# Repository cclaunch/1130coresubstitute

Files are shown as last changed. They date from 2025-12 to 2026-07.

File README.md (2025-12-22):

1130 Core Substitute

This project is intended for IBM 1130 systems where a core memory compartment is nonfunctional and unlikely to be restored to reliable operation. The printed circuit board is inserted at the top of the core compartment and is connected via the top cables T1, T3 and T4 that are normally plugged into the SLT board for the compartment. 

It is based around a Magnetoresistive Random Access Memory (MRAM) which provides the same non-volatility as core memory even after two decades sitting without power. MRAM has infinite read and write cycles, unlike flash memory, thus it is very suitable for use in a computer.

One would disconnect the four voltage rails to the core memory compartment (+6, +3, -3 and +12) so that the compartment itself is inert. The new PCB fits in the space at the top of the compartment where the top cables were connected. It requires only three wires to connect it to the +12V and ground rails of the 1130 system. 

This first version was developed for a particular 1130 system I restored, one with 8K of 3.6 microsecond core. This fits in the B gate in compartment C1. The SLT board has a core memory stack mounted in the center and SLT cards arrayed around the outside of the stack to provide the logic to make the core work. 

The same board can be enhanced to connect to cable T2, for machines with more than 8K of memory (or any 2.2 microsecond core memory model). Assuming the machine is configured for larger memory sizes so that the proper address lines are implemented in the device controllers and central processor, this single board could implement up to the maximum 32K word memory capacity. I will outline how the enhancement might be accomplished in a document in this repository.

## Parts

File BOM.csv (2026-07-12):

Index | DigiKey Part # | Manufacturer Part Number | Manufacturer | Description | Quantity | Unit Price | Extended Price
1 | 819-1007-ND | MR0A16AYS35 | Everspin Technologies Inc. | IC RAM 1MBIT PARALLEL 44TSOP2 | 1 | $16.12 | $16.12
2 | 296-12358-1-ND | SN74LV240APWR | Texas Instruments | IC BUFFER INVERT 5.5V 20-TSSOP | 2 | $0.85 | $1.70
3 | 1727-5965-1-ND | 74HC86PW | Nexperia USA Inc. | IC GATE XOR 4CH 2-INP 14TSSOP | 4 | $0.23 | $0.92
4 | 296-1221-1-ND | SN74LVC08APWR | Texas Instruments | IC GATE AND 4CH 2-INP 14TSSOP | 5 | $0.40 | $2.00
5 | 296-1187-1-ND? | SN74HC00DR? | Texas Instruments | IC GATE NAND 4CH 2-INP 14SOIC | 1 | $0.23 | $0.23
6 | A100889CT-ND | 5-87623-4 | TE Connectivity | SLT connector pins | 72 | $0.65 | $46.64
7 | 399-C0603C104K3RACTUCT-ND | C0603C104K3RACTU | Kemet | CAP CER 0.1UF 25V X7R 0603 | 17 | $0.03 | $0.44
8 | 497-17239-1-ND | LDL1117S33R | STM Microelectronics | IC REG LINEAR 3.3V 1.2A SOT-223 | 1 | $0.36 | $0.36
9 | 1276-1066-1-ND | CL21B105KAFNNNE | Samsung | CAP CER 1UF 25V X7R 0805 | 2 | $0.08 | $0.16
10 | 587-2990-1-ND | TMK212AB7475KG | Tayo Yuden | CAP CER 4.7UF 25V X7R 0805 | 3 | $0.23 | $0.69
11 | BSV52LT1G | BSV52LT1G | OnSemi | TRANS NPN 12V 0.1A SOT23-3 | 18 | $0.29 | $5.22
12 | ERA-6AEB202V | ERA-6AEB202V | Panasonic | RES SMD 2K OHM 0.1% 1/8W 0805 | 18 | $0.06 | $1.10
13 | 497-6447-2-ND | LD1117S50TR | STM Microelectronics | IC REG LINEAR 5V 1.2A SOT-223 | 1 | $0.39 | $0.39
14 | RMCF0805FT330KCT-ND | RMCF0805FT330K | Stackpole Electronics Inc | RES 330K OHM 1% 1/8W 0805 | 1 | $0.39 | $0.39
15 | 296-11607-1-ND | SN74LVC1G14DBVR | Texas Instruments | IC INVERTER 1CH 1-INP SOT23-5 | 1 | $0.12 | $0.12
16 | 1286-1205-ND | 410-376 | DIgilent | CMOD S7: BREADBOARDABLE SPARTAN7 | 1 | $99.00 | $99.00
17 | 2946-236-101-ND | 236-101 | Wago | STACKABLE PCB TERMINAL BLOCK; 2. | 1 | $1.22 | $1.22
18 | 2946-236-102-ND | 236-102 | Wago | PCB TERMINAL BLOCK; 2.5 MM; PIN | 1 | $2.49 | $2.49
19 | 478-TAJP106K010TNJCT-ND | TAJP106K010TNJ | Kyocera | 10 µF Molded Tantalum Capacitors 10 V 0805 (2012 Metric) | 1 | $1.01 | $1.01
 |  |  |  | Fedex Digikey shipment charge | 1 | $6.99 | $6.99
 |  |  |  | tax |  |  | $12.61
 |  |  |  | PCB + shipping charge | 1 | 90 | $90.00
 |  |  |  | Stencil for solder paste |  |  | $0.00
 |  |  |  |  |  | subtotal | $289.81

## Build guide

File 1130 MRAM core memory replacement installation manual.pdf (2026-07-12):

## Installation Instructions

Core Memory Replacement for IBM 1130

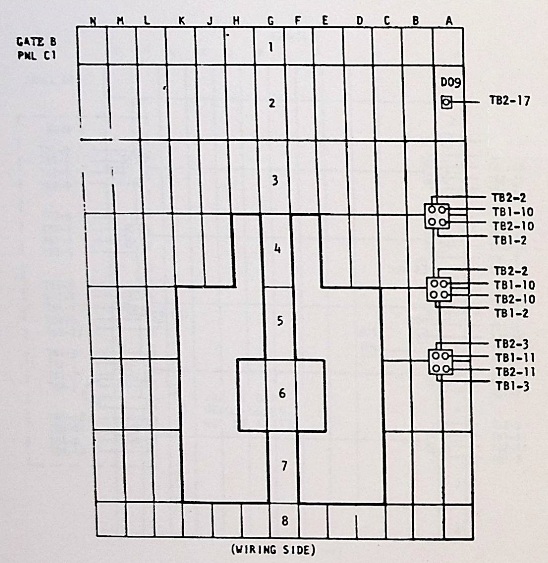
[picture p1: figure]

Carl V Claunch | 1 | Version 1

1130 models this board can be used with

This board is designed to be used with 1130 models 1A and 1B, those with a 3.6 microsecond core memory technology and capacities of 4K or 8K words. These models have the memory completely contained in gate B, compartment C1 of the 1131 frame.

Preparation of the machine before mounting the board

1. Remove the side connectors that deliver power to the SLT board for gate B compartment C1. Three connectors have four pins (+6, -3, +3 and ground) and you have a single pin connector (+12V).

Core Memory Replacement for IBM 1130

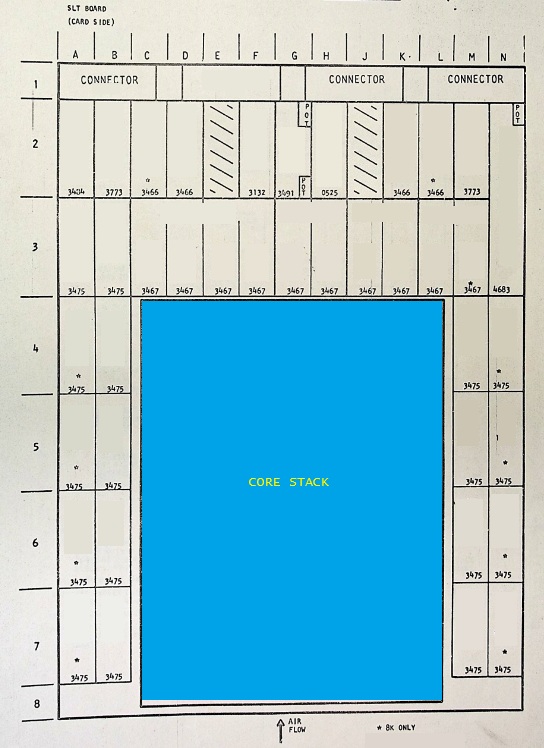
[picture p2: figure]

Carl V Claunch | 2 | Version 1
2. Remove and save the SLT cards surrounding the core memory stack. There are cards to be removed from slots A2, B2, C2, D2, F2, G2, H2, K2, L2, M2, N2, A3, B3, C3, D3, E3, F3, G3, H3, J3, K3, L3, M3, N3, A4, B4, M4, N4, A5, B5, M5, N5, A6, B6, M6, N6, A7, B7, M7 and N7.

Core Memory Replacement for IBM 1130

Carl V Claunch | 3 | Version 1
3. Open the metal grill across the top of gate B and temporarily put it aside. You are looking down into the card compartments.
4. Pull the white cables off the connector positions at T1, T3 and T4. There should be no cable attached to T2; if there is, this is not one of the models of 1130 that are supported by this board.
5. Mount the 1130 MRAM board in place inside the opening of compartment C1 from the top so that the SLT pins stick out towards the SLT card side of the board and so that it sits with the original connector pins for T1, T3 and T4 behind the new PCB.

Two mounting holes on the PCB are used to attach L shaped brackets. The long end has a bolt and nut that passes through the PCB holes. The shorter end fits under the grill on top of gate B and is held in place when the grill is screwed down.

6. Install cables T1, T3 and T4 onto the PCB, being careful to check that two two rows and 12 columns of pins are all inside the cable connectors.
7. Connect the red wire coming from the 1130 power supply to the + input terminal on the board Connect the black wire coming from the 1130 power ground strip to the - input terminal on the board.
8. Be certain to install the red and black wire pair onto the PCB with the red (+) wire on the innermost terminal screw and the black wire to the other screw terminal positions.

Core Memory Replacement for IBM 1130

Carl V Claunch | 4 | Version 1
9. Add a braided ground wire, one with as many fine strands as possible. This runs parallel to the black ground wire. This is critical to reducing impedance at higher frequencies that cause some ground bounced.
10. Route the red, black and braided ground wires out the right side of compartment when viewing the core memory stack. Bring them down to the terminal blocks at the bottom of this gate.
11. Put ring terminals on the ends of the wires after trimming them to length to where they will attach.

Core Memory Replacement for IBM 1130

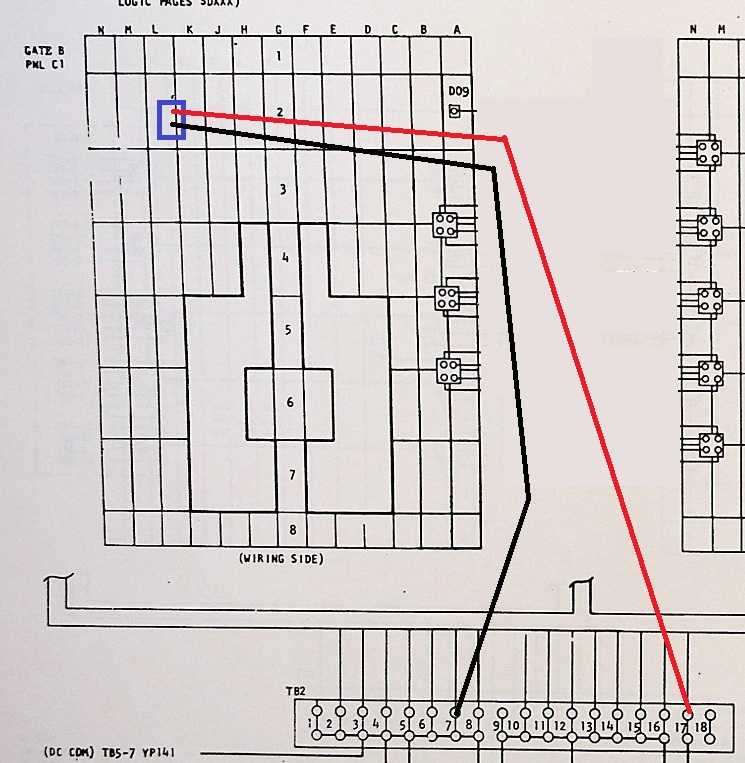
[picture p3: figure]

Carl V Claunch | 5 | Version 1
12. Put the black wire ring terminal on TB2 positions 1 through 8, whichever position is easier to add to. Similarly attach the braided ground wire to one of these positions.
13. Put the red wire’s ring terminal on TB2 position 17.

Core Memory Replacement for IBM 1130

Carl V Claunch | 6 | Version 1
14. Close the card compartment cover and reattach the top metal grill, positioning the L brackets under the grill to keep the PCB suspended underneath.

Testing Procedure Number 1

Turn on power to the machine.
Open the top right cover of the 1131 and turn on the Storage Load switch just behind the usage meter.
Set all the console entry switches on the front of the typewriter to 1 except for switches 0 and 15 which remain at 0.
Push the PROG START button near the keyboard.
The machine should be cycling through all addresses rapidly
Turn the rotary mode switch to SI for a moment to stop the process Switch off the Storage Load switch near the usage meter
Switch on the Storage Display switch near the usage meter
Turn the rotary mode switch to RUN
Push the Prog Start button near the keyboard
The machine should be looping through memory reading it
If it stops and the red Parity Stop lamp is on near the keyboard, something is wrong; stop testing
Turn the rotary mode switch to SI temporarily and then to RUN Turn off the Storage Display switch near the usage meter

Core Memory Replacement for IBM 1130

Carl V Claunch | 7 | Version 1

Testing Procedure Number 2

Open the top right cover of the 1131 and turn on the Storage Load switch just behind the usage meter.
Set all the console entry switches on the front of the typewriter to 0. Push the PROG START button near the keyboard.
The machine should be cycling through all addresses rapidly
Turn the rotary mode switch to SI for a moment to stop the process Switch off the Storage Load switch near the usage meter
Switch on the Storage Display switch near the usage meter
Turn the rotary mode switch to RUN
Push the Prog Start button near the keyboard
The machine should be looping through memory reading it
If it stops and the red PARITY STOP lamp is on near the keyboard, something is wrong; stop testing
Turn the rotary mode switch to SI temporarily and then to RUN Turn off the Storage Display switch near the usage meter

Core Memory Replacement for IBM 1130

Carl V Claunch | 8 | Version 1

Testing Procedure Number 3

Turn the rotary mode switch to Load
Set the console entry switches (CES) to 0000 0001 0000 0000 Push the LOAD IAR button near the keyboard
Push the PROG START button near the keyboard
Set the CES to 0000 0001 0000 0001
Push the PROG START button near the keyboard Set the CES to 0000 0001 0000 0010
Push the PROG START button near the keyboard Set the CES to 0000 0001 0000 0011
Push the PROG START button near the keyboard Set the CES to 0000 0001 0000 0100
Push the PROG START button near the keyboard Set the CES to 0000 0001 0000 0101
Push the PROG START button near the keyboard Set the CES to 0000 0001 0000 0110
Push the PROG START button near the keyboard Set the CES to 0000 0001 0000 0000
Push the LOAD IAR button
Turn the rotary mode switch to Display
Push the PROG START button near the keyboard
The Storage Buffer Register (SBR) should read 0000 0001 0000 0000 Push the PROG START button again
The SBR should be 0000 0001 0000 0001
Push the PROG START button again
The SBR should be 0000 0001 0000 0010 Push the PROG START button again The SBR should be 0000 0001 0000 0011 Push the PROG START button again The SBR should be 0000 0001 0000 0100 Push the PROG START button again The SBR should be 0000 0001 0000 0101

Core Memory Replacement for IBM 1130

Carl V Claunch | 9 | Version 1

Push the PROG START button again The SBR should be 0000 0001 0000 0110 Push the PROG START button again
The SBR should be 0000 0001 0000 0111
Push the PROG START button again
The SBR should read 0111 1111 1111 1110
If the results are not correct, stop. There is a problem. Turn the rotary mode switch to RUN

Core Memory Replacement for IBM 1130

Carl V Claunch | 10 | Version 1

Testing Procedure Number 4

Using the core memory loader, load the Core Memory diagnostic program 3B0 or 3B1 into core
Set the CES to the IAR that is displayed by the core memory loader when it has finished with the diagnostic file
Turn the rotary mode switch to LOAD
Push the LOAD IAR button near the keyboard
Turn the rotary mode switch back to RUN
Push the PROG START button near the keyboard
Follow the directions for the diagnostic to verify memory is good. The console printer will print END MEMORY TEST and the 1130 will be waiting with the appropriate wait code in the SBR.

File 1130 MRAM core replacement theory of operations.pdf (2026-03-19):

## Theory of Operation

Core Memory Replacement for IBM 1130

Carl V Claunch | 1 | Version 1

Summary

This is designed as an easy swap for an 8K core memory in an IBM 1130 system. Gate B compartment C1 contains the original core memory stack plus SLT cards for the memory function.

This PCB is mounted inside the card side of the compartment where the three connector cables T1, T3 and T4 plug into the core memory compartment.

Those three cables are instead plugged into this PCB and a connection is made to the 1130 +12V power supply. Compartment C1 is disconnected from the +6, +3, -3 and +12V supplies of the 1130 as all its functions are completely replaced by this board.

The board implements non-volatile storage with 8K words of 18 bit storage, providing 16 data bits plus parity bits P1 and P2. This board retains the content of memory for up to 20 years without power being supplied.

A Field Programmable Logic Array (FPGA) is used to detect the 1130 control signals and to generate internal control signals that drive the chips on this board. This is implemented on a Digilent CMOD S7 board that sits on my printed circuit board as a daughter card.

Core Memory Replacement for IBM 1130

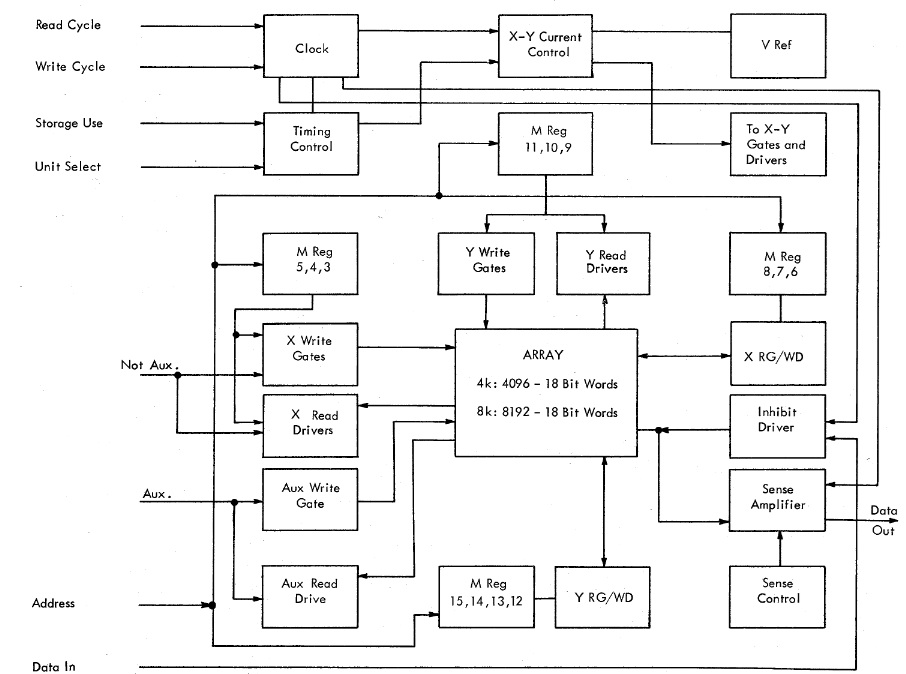
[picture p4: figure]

Carl V Claunch | 2 | Version 1

Interface between the 1130 system and the core memory

The IBM 1130 provides 3 control signals to the core memory compartment - Storage Use, Storage Read and Storage Write.

Cable T3 delivers a 13-bit memory address which represents the word within the 8K core memory that is being addressed. The low order bit of an address or a data word is numbered 15, with bit 0 referring to the highest order bit (usually a sign bit) of the data word. The Storage Address Register (SAR) bits 3 to 15 are used to select one of 8192 unique word addresses.

Core Memory Replacement for IBM 1130

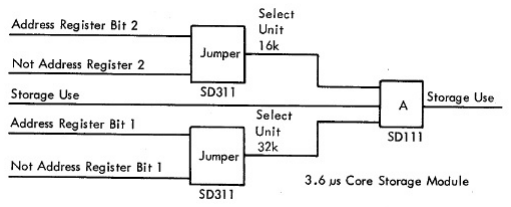
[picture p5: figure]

Carl V Claunch | 3 | Version 1

For machines configured with larger memories, up to 32K words, the 1130 has multiple core memory compartments. These are in gate D compartment A1, gate D compartment B1, gate E compartment A1 and gate E compartment B1 depending on how many increments of 8K are installed.

The 100 ns pulse Storage Select indicates that the SAR address is within the 8K range of memory that this compartment manages. For a 32K machine, Storage Select is only emitted for the compartment matching the full SAR address. On the 8K models such as this board is designed to replace, Storage Select is not implemented.

The jumpers referenced above determine what the two high order address bits are for a particular core module (compartment). With both bits at 0, this addresses words 0 to 8,191. Other combinations select other compartments:
01 (8,192 to 16,383),
10 (16,384 to 24,575)
11 (24,576 to 32,767).

Core Memory Replacement for IBM 1130

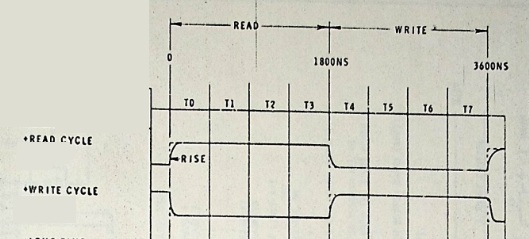
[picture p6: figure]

Carl V Claunch | 4 | Version 1

Any time the 1130 CPU clock is running, the signals Storage Read and Storage Write are alternating. Each is active for 1.8 or 1.1 microseconds (depending on whether this is a 3.6 uS or a 2.2 uS model).

The final control signal Storage Use is active when the CPU wants to read and write to memory but is turned off when no memory access is desired. Example - To branch to an interrupt handler, the CPU forces in a Branch and Store IAR (BSI) instruction while turning off Storage Use so that nothing comes from memory during that 3.6 or 2.2 uS processor cycle.

There is always a SAR address incoming on cable T3. When Storage Select arrives and Storage Use are asserted, the core memory compartment will perform a read of a word during the time that Storage Read is active, then perform a write of a word when Storage Write is active.

Core Memory Replacement for IBM 1130

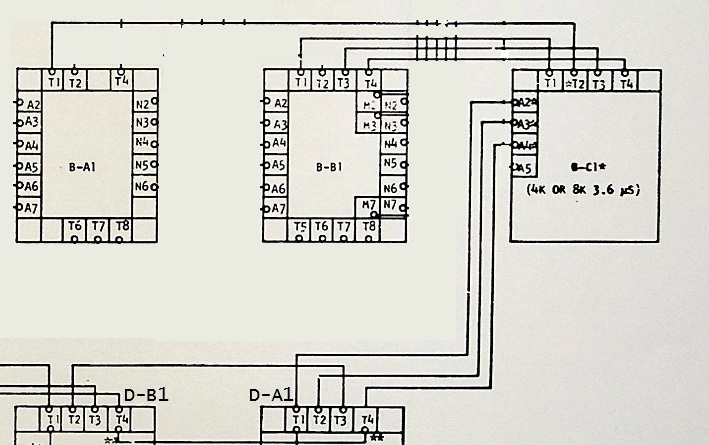
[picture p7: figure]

Carl V Claunch | 5 | Version 1

The data value to be written into memory is delivered on cables T1 and T4. This is called the Storage Buffer Register (SBR or B register). Sixteen data bits B0 to B15 are transmitted along with the two parity bits P1 and P2.

When a word is read, while Storage Read is active, sense lines S0 through S17 will generate a pulse for any bit of the word that contained the binary value 1. The pulse is generated somewhere during the time Storage Read is active. It is not synchronous to the CPU clock or circuitry. Sense lines are output on cables T1 and T4.

In fact the core memory compartment is not synchronous to the 1130 other than by seeing the alternating Storage Read and Storage Write signals. The core memory captures the SBR value sometime during the cycle when Storage Write is active. The CPU does not change the B register or the SAR values except at the start of the Storage Read or Storage Write signals.

Core Memory Replacement for IBM 1130

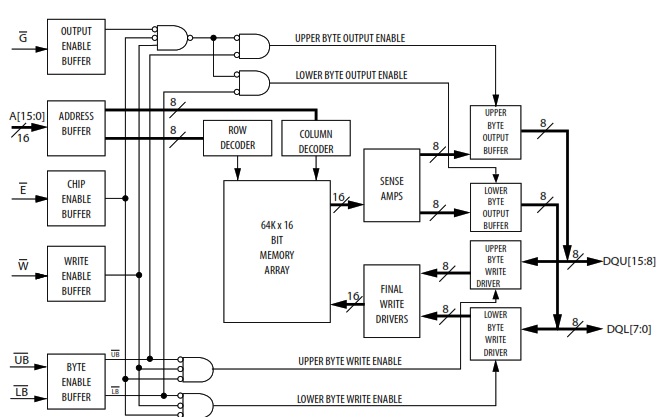
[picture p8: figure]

Carl V Claunch | 6 | Version 1

MRAM chip at the heart of the replacement board

One Magnetorestrictive Random Access Memory chip is installed on the board, with a capacity of 64K words of 16 bits. This technology is non-volatile, just as is core memory, meaning the contents from its prior use are still there when the machine is powered up.

The Everspin MR0A16A chip guarantees that the contents remain preserved for at least 20 years after power was last removed. The chip has no wear limits - it can be read and written as much as is desired with no impact on the chip life.

Core Memory Replacement for IBM 1130

Carl V Claunch | 7 | Version 1

Finally, it is designed to be accessed very similar to Static Random Access Memory (SRAM) chips. The chip completes a read or a write in 35 nanoseconds, far faster than is required by an 1130 system.

The SAR address bits are directly connected to the MRAM chip. Its behavior is determined by three chip control signals - ~E, ~W and ~G.

~E enables the chip to perform some function when it is asserted low.

~W directs the chip to write the data on its 16 bidirectional data pins into the location determined by the address bit pins.

~G controls the bidirectional data pins. When asserted low, the contents of the memory word at the location determined by the address bit pins is output on the 16 pins. When ~G is deasserted (logic high level), the output pins are put into high impedance mode.

Thus to write the ~G must be deasserted and the data word driven onto the 16 data pins. To read, ~G is asserted and the memory contents drive the 16 data pins.

Core Memory Replacement for IBM 1130

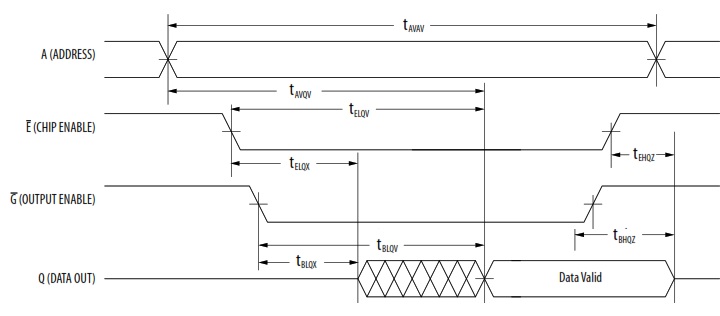
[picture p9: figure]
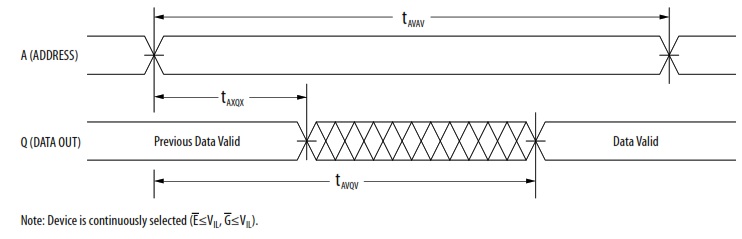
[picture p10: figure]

Carl V Claunch | 8 | Version 1

The chip is not sensitive to how long the ~G, ~E and ~W pins are asserted, other than the minimum 35 nanosecond time necessary for the chip to complete the read or the write.

Above is the mode I will use for reads - imagine from the point that data is valid we sit and wait about 400 nanoseconds before sampling the data values. They won’t change no matter how long it sits in this state, as shown by the read alternative sequence below:

Core Memory Replacement for IBM 1130

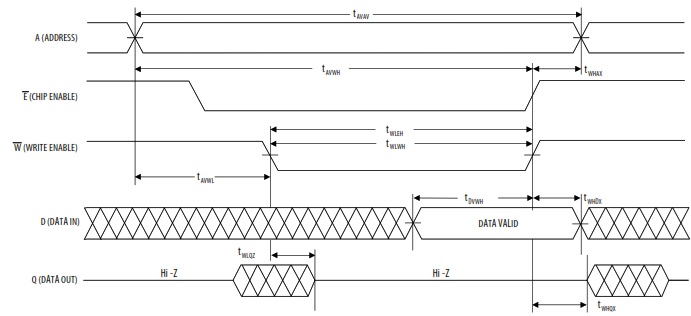
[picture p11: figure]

Carl V Claunch | 9 | Version 1

For writes I will use a version of the pattern below:

In this case, ~E is asserted for about 400 nanoseconds before I assert ~W during the 80 ns pulse. That is longer than the 35 ns max time needed for the write to complete.

Core Memory Replacement for IBM 1130

Carl V Claunch | 10 | Version 1

Dealing with parity bits

The core memory in the IBM 1130 is relatively error prone, thus parity bits are included in the core stack and used by the CPU. The modern MRAM chip is so reliable that we don’t need parity checking.

Thus when we write a word into memory we only capture the 16 bits of the SBR and ignore the parity bits produced by the CPU. When we return a word from memory during a read, we must present the two parity bits to the CPU because it will test them to check for errors.

Thus, the two parity bits are generated by the board from the 16 data bits retrieved from the MRAM chip. The CPU is presented 16 data and 2 parity bits on sense bits S0 to S17.

The parity scheme in the IBM 1130 is to produce a parity bit for each half of the word. Parity bit P1 is calculated over the values in data bits 0 to 7, while parity bit P2 is generated from the values in data bits 8 to 15.

The 1130 uses odd parity. This means that the number of bits that have a value of 1 in the half of a word, plus the associated parity bit, must be an odd number. If the eight bits are 00000000 then the parity bit is turned on to produce an odd count. If the eight bits were 00001000 then the parity bit is set to 0.

Core Memory Replacement for IBM 1130

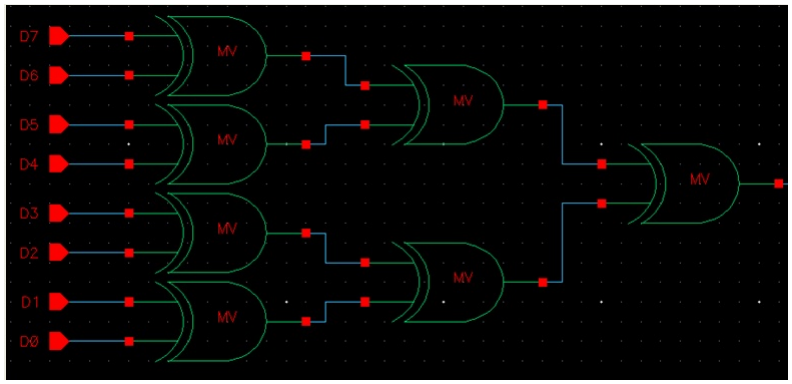
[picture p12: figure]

Carl V Claunch | 11 | Version 1

This is generated with a cascade of exclusive-OR (XOR) gates. The output of XOR is 0 when the two inputs agree, a 1 when they differ. It doesn’t matter if the two bits are 00 or 11, the agree. Similarly, whether 01 or 10, they disagree.

An XOR gate compares each pair of bits in the halfword - 0 and 1, 2 and 3, etc. The outputs of those four XOR gates are connected to two more XOR gates, comparing pairs of of the four XOR gate outputs. The two gate outputs of the second level of XORS are connected to a single XOR in the third level that produces the inverted value of the parity bit.

When the output of the XOR cascade is 1, it means we already have odd parity thus the parity bit must be zero. Another XOR is used with one input tied to high to create an NOT gate for the output.

Core Memory Replacement for IBM 1130

Carl V Claunch | 12 | Version 1

The 1130 CPU uses the same three level chain of XOR gates to do its parity generation and parity checking. In this design, we don’t bother storing the generated parity bits along with the SBR, but we recreate the two parity bits during a read so that the 1130 CPU can validate correct parity.

Core Memory Replacement for IBM 1130

Carl V Claunch | 13 | Version 1

Connecting SBR signals to the bidirectional data pins

The SBR signals coming in over cables T1 and T3 are unidirectional - they are driven by the 1130 CPU at all times. We put buffer chips between the SBR and the MRAM data pins - when the buffer is enabled it drives the MRAM data pins with the value coming from the SBR.

When disabled, the buffer chip goes to high impedance. This allows the MRAM chip to drive values on the pins during a read. The SBR is isolated by the buffer chip whose inputs are unidiretional just like SBR. The FPGA controls the buffer enable.

Because the SBR bits from the CPU are inverted, the buffer we use will invert the signals before applying them to the bidirectional data pins of the MRAM chip. Thus the word in memory is not inverted.

The FPGA produces the MRAM chip ~W control signal to perform the write. It also generates the buffer enable when in a storage write phase of the memory cycle, passing the SBR bits on to the MRAM data pins.

The ~G control signal that drives output from the MRAM chip onto its data pins is emitted by the FPGA- when not in a storage write phase we have the memory contents driven on the data pins.

Chip enable signal ~E is also produced by the FPGA based on a state machine for managing reads and writes.

Core Memory Replacement for IBM 1130

Carl V Claunch | 14 | Version 1

Producing pulses on the sense lines only when the bit was 1

The MRAM chip provides a steady word value on its bidirectional data pins once the read has completed, but the 1130 expects a short pulse for bits that had the value 1.

The FPGA outputs a timed pulse to gate each of the 16 data and 2 parity bits. Currently the FPGA controls sets of three bits in a cycle, skewing the setting of bits into the SBR to minimize total current sinking by the board at any instant.

The data value from the MRAM data pins is passed though
AND gates and an NPN transistor, so that only when a data pin is 1 and the pulse is active will be output a logic low to the sense line.

The two recreated parity bits are treated similarly, so that pulses are emitted for any parity bit that has a 1 value.

This matches the inverted logic that the 1130 CPU expects - a low going brief pulse will set the SBR to a value of 1. If the memory bit value was 0, then no pulse is emitted from core memory and the SBR bit stays at 0.

The 1130 has pullup resistors on the sense output lines keeping them at +3V unless they are asserted by pulling the line down to ground. We use a transistor in an open collector configuration to pull the 1130 sense output line down when the pulse is active.

Core Memory Replacement for IBM 1130

Carl V Claunch | 15 | Version 1

Reading and writing timing consistent with 1130 core memory

The timing of a core memory module is not clock synchronous and the sense pulses fore each bit can arrive at slightly different times. About halfway through the Storage Read signal duration, the sense pulses are typically produced, just before the T2 clock phase.

The actual values are on the MRAM data bus before the T1 clock cycle and will remain on those pins throughout the entire time Storage Read is active. This is not a problem for the
MRAM chip as the data value remains active as long as the address bits don’t change and both ~E and ~G are asserted. . Our AND gates just sample the data pin value when our 80 ns pulse is high.

The state machine in the FPGA synchronizes the 1130 control signals Storage Use, Storage Read and Storage Write to avoid metastability issues and align them with the 200MHz clock of the FPGA. This introduces about 25 nanoseconds of delay before the FPGA acts upon the control signal.

The FPGA controls the ~E, ~G, ~W and ~Gate (buffer enable) lines based on the state machine. It is designed to meet or exceed the timing requirements of the MRAM chip while simulatenously being consistent with the timing of the IBM core memory it is replacing.

Core Memory Replacement for IBM 1130

Carl V Claunch | 16 | Version 1

A read involves setting bits in the SBR for every bit that has a 1 value, in pulses of 80 nanoseconds skewed in six groups of three bits. With IBM core memory, it completes before the T2 clock of the 1130 begins. Each bit’s sense pulse can arrive asynchronously to the other bit’s pulses.

A write is completed before the start of the T5 clock cycle, earlier than with the 1130 but nothing in the 1130 depends on the actual write process taking longer. The 1130 holds the address and the SBR bit values steady during the time Storage Write is active.

Core Memory Replacement for IBM 1130

Carl V Claunch | 17 | Version 1

+12V present and Storage Use must both be asserted in order for the FPGA to assert the ~E control pin low. This ensure the
MRAM chip only does reads or writes when the CPU wants memory to be accessed and the CPU is not in the midst of powering down or up.

When the Storage Write signal is asserted, the SBR contains the data word to be written into memory at the location specified by the SAR. The values on SBR and SAR stay constant throughout the Storage Write 1.8 uS duration.

Behavioral difference from original core memory

No difference is undetectable by any software running on the IBM 1130 or any peripheral device connected to the machine. No diagnostic program will detect this, nor will any timing be altered.

The original IBM core memory stack is a destructive read memory, which is why the 1130 always performs a storage cycle of a read followed by a write(back). When using the 1130 in any mode other than Single Step, entire read-then-write cycles are performed thus no difference can be detected.

However, Single Step mode advances through the T clock steps T0 to T7, where the read part of a storage cycle occurs during the first four clock steps and the write(back) happens in the last four steps. It is possible to step partway through a storage cycle, then switch the mode or hit the Reset button.

Core Memory Replacement for IBM 1130

Carl V Claunch | 18 | Version 1

This leaves the currently addressed storage location as all zeros with bad parity on original core memory, but with MRAM the original value and good parity remain. If the operator stopped single stepping during the read part of the cycle then reset the machine so that it eventually read the location that was zeroed, a parity error would be detected.

This is the only situation in which the difference should be observable between this core memory substitute and the original IBM memory stack.

Core Memory Replacement for IBM 1130

Carl V Claunch | 19 | Version 1

Memory content safety during power shutoff

The board is connected to the IBM 1130’s +12VDC supply line. The power on and power of sequencing of the 1130 ensures that the +12V line is connected only when all the primary SLT logic rails are at correct levels (+6, -3 and +3).

When the power switch is turned off, a relay disconnects +12V while the SLT power supplies continue to provide good logic voltages. Because it is switched through a relay, the shutoff is almost instantaneous. The IBM core memory modules are designed to rely on the 12V relay to protect against spurious writes on power issues, thus we should be equally safe.

One other case exists with the 1130 power supplies - failure of one of the voltage rails due to some kind of malfunction. As the SLT logic levels degrade a sensing card will shut down the relay for the +12V and then lock out the machine.

A resistor divider on the 12V input is connected through an
AND gate, so that use of the MRAM is revoked if 12V is no longer present from the CPU. Thus any energy in our power supply to the MRAM chip and other logic chips on the board will not produce any spurious write to memory.

Power supply circuit

Linear regulator chips on the board generates our 3.3V rail for the chips and 5V for the FPGA board. . They are fed by the +12V supply from the IBM 1130.

Core Memory Replacement for IBM 1130

Carl V Claunch | 20 | Version 1

Variations that could support larger and faster memory sizes

If the 1130 system is a model that uses the newer faster IBM 2.2 microsecond core memory modules, we would have to adjust the resistor and capacitor values on the first stages of both Monostable Multivibrator chains to attain a shorter delay pulse of about 500 ns instead of the 800 ns used with the 3.6 uS core type.

This design is currently correct for a 8KB 3.6 uS model of the 1130, where the core memory is contained in gate B compartment C1. It will need changes for other configuratons.

The memory modules are moved to different locations with larger memory models. These sit in gates D and E, contained in the extension frame attached to the left of the console keyboard in what is informally called the blister. Each gate has room for two compartments; each compartment holds an 8K memory module.

Even the smallest 2.2 uS memory configurations are contained in gate D compartment A1 rather than gate B compartment C1. The signals that come into gate B compartment C1 through T1, T3 and T4, plus cable T2, would flow through some additional SLT logic in that compartment and then exit over other cables that run to gates D and E.

The cables coming out of gate B compartment C1 for these new configurations are connected at A2, A3, A4 and A5 of B-C1. They run to connectors at the top of the compartments on gates D and E. Cable A2 handles extra signals for 2.2 uS models.

Core Memory Replacement for IBM 1130

Carl V Claunch | 21 | Version 1

Larger memory would require the additional SLT logic implemented in gate B compartment C1. B-C1 no longer holds a core memorystack and related logic cards; it has a different purpose for the alternate configurations. Thus our board would have to connect in gate D compartment A1 even if we replace all the memory in all the compartments of the blister.

Our board does not have pins to connect to cable T2, but that is used to send the appropriate Storage Selection bits to let each compartment respond to its range of 8K addresses out of the total. We need those bits to complete the full addressing of up to 32K words. They should arrive over the cables into gate D but the details are still to be worked out.

Versions of the 1130 with only a single 4K or 8K 3.6 microsecond storage capacity have the memory in gate B compartment C1. All others use the Expanded Storage feature, which puts logic in B-C1 and moves the Storage Select signal over to cable T2 for 2.2 uS memories.

The MRAM chip has plenty of capacity but we would have to update its memory address pin connections and deal wtih the Storage Selection signals appropriately so that we could answer for all replacement core memory compartments.

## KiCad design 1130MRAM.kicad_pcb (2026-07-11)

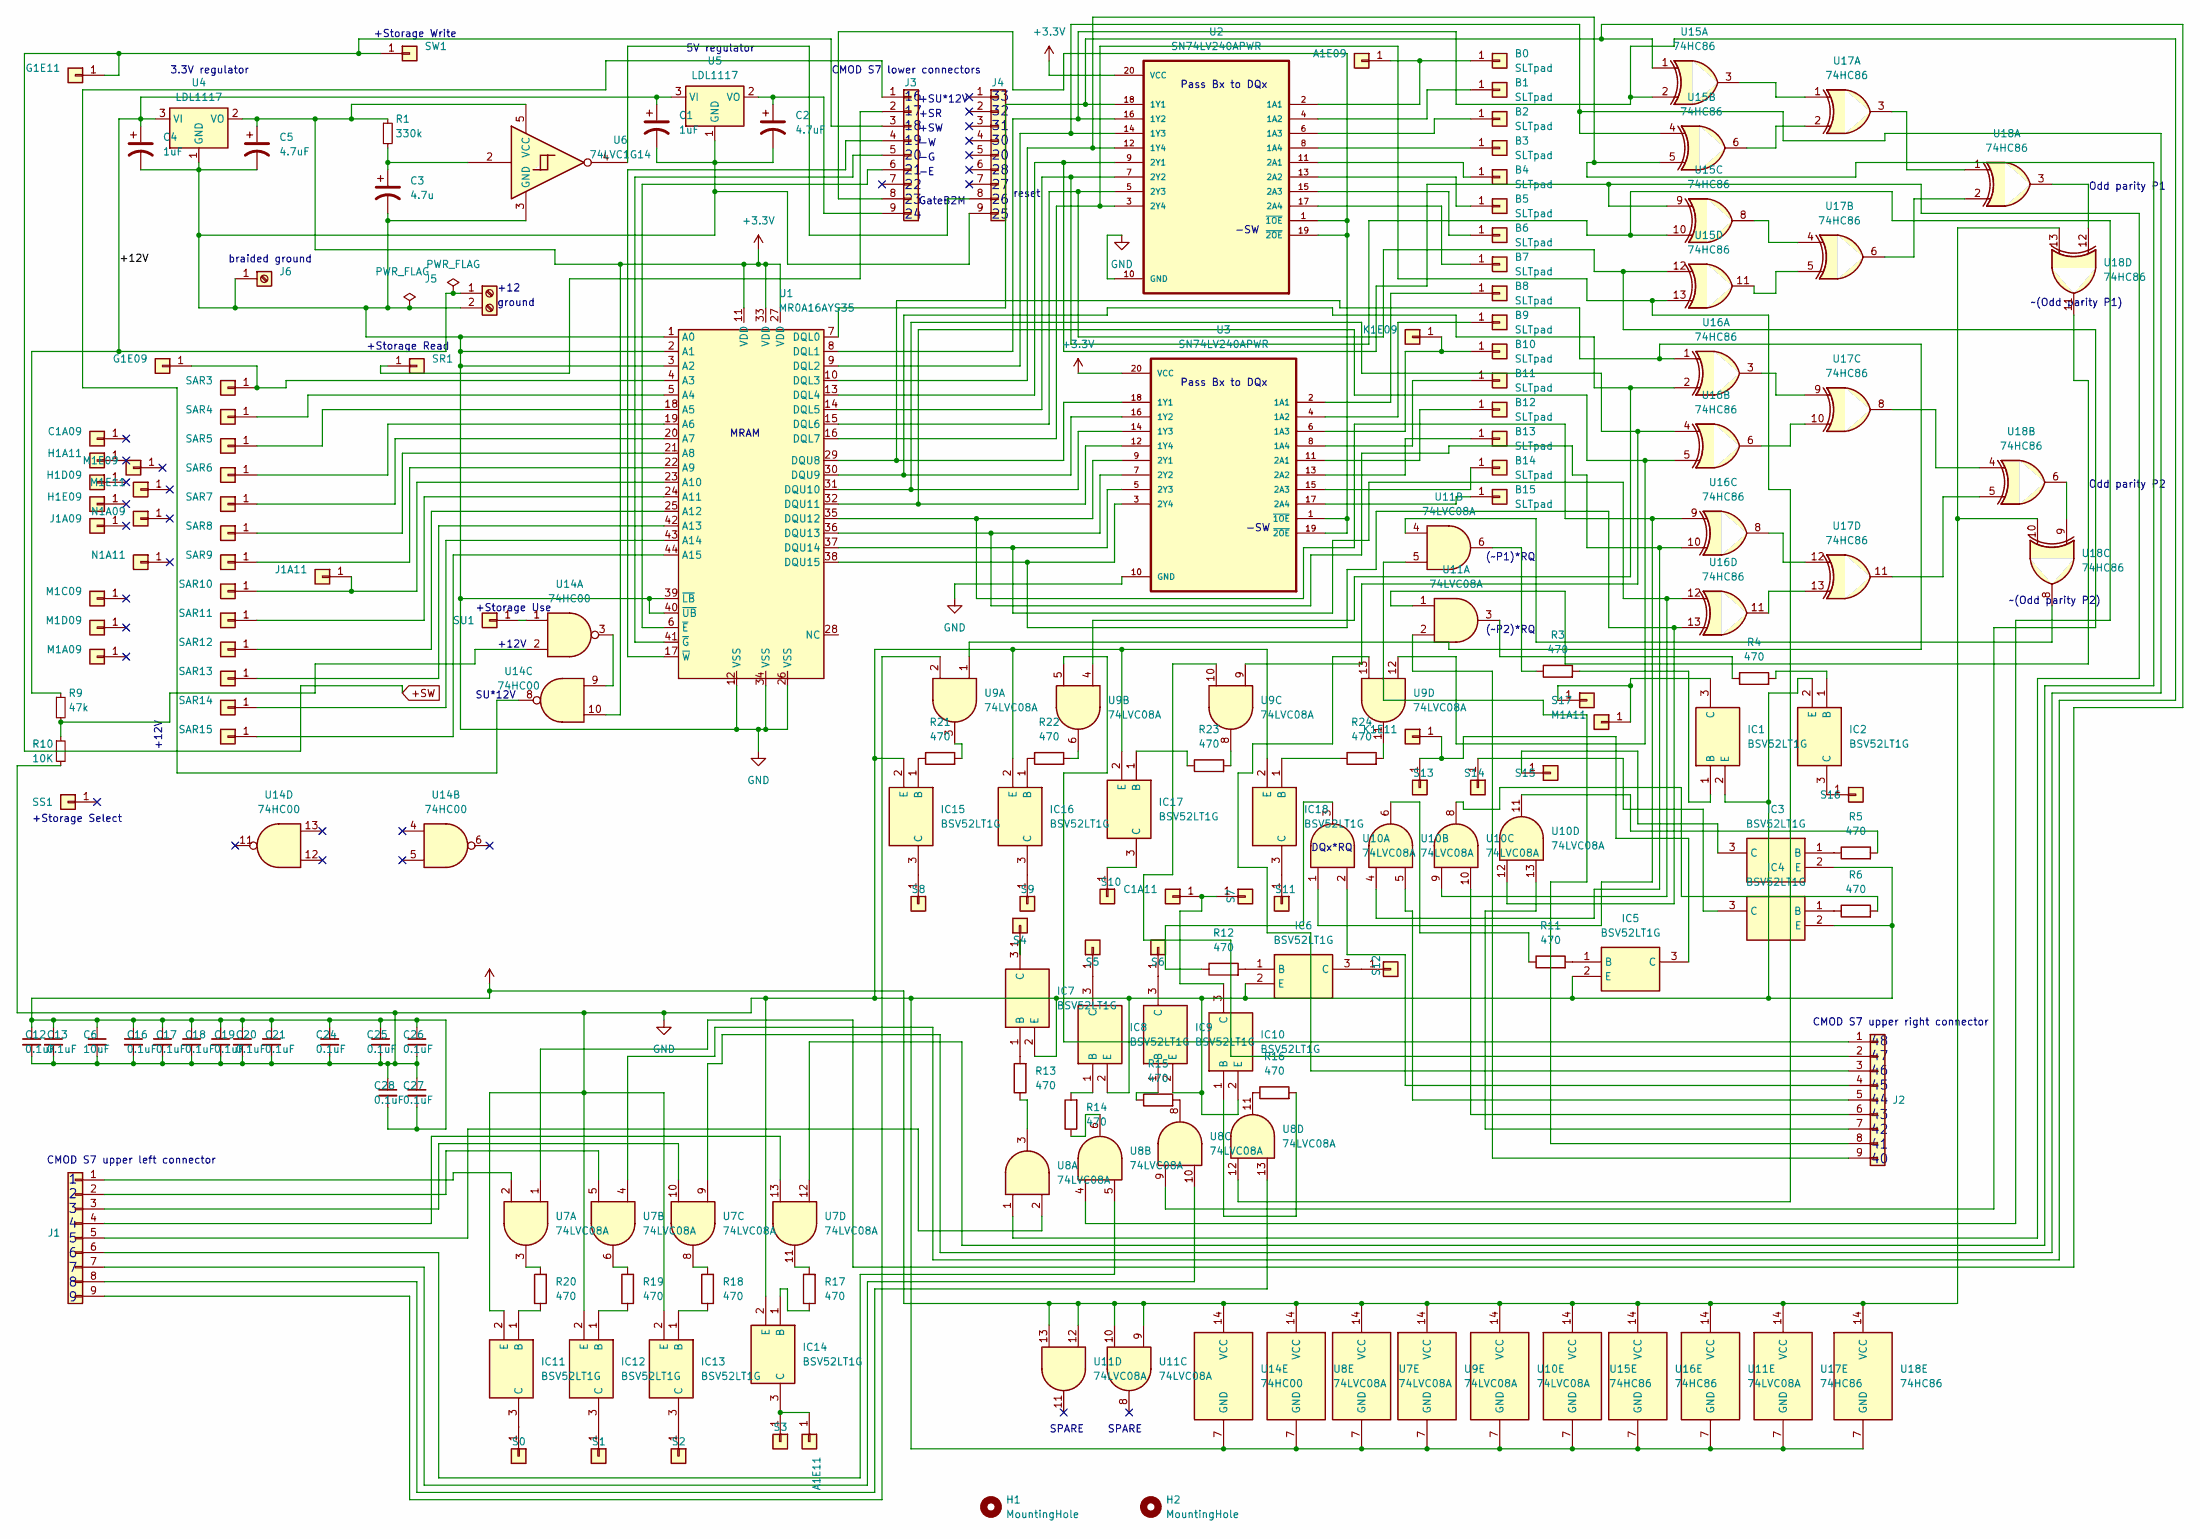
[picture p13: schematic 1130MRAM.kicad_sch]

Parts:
A1E09, A1E11: SLTpad; SLT
B0, B1, B2, B3, B4, B5, B6, B7, B8, B9, B10, B11, B12, B13, B14, B15: SLTpad; SLT
C1, C4: 1uF; C_0805_2012Metric
C1A09, C1A11: SLTpad; SLT
C2, C5: 4.7uF; C_0805_2012Metric
C3: 4.7u; C_0805_2012Metric
C6: 10uF; C_0805_2012Metric
C12, C13, C16, C17, C18, C19, C20, C21, C24, C25, C26, C27, C28: 0.1uF; C_0603_1608Metric
G1E09, G1E11: SLTpad; SLT
H1, H2: MountingHole; MountingHole_4.3mm_M4
H1A11, H1D09, H1E09: SLTpad; SLT
IC1, IC2, IC3, IC4, IC5, IC6, IC7, IC8, IC9, IC10, IC11, IC12, IC13, IC14, IC15, IC16, IC17, IC18: BSV52LT1G; SOT-23; Manufacturer_Part_Number BSV52LT1G; Mouser Part Number 863-BSV52LT1G
J1, J2, J3, J4: Conn_01x09_MountingPin; PinSocket_1x09_P2.54mm_Vertical
J1A09, J1A11: SLTpad; SLT
J5: Screw_Terminal_01x03; TerminalBlock_WAGO_236-102_1x02_P5.00mm_45Degree
J6: Screw_Terminal_01x01; TerminalBlock_WAGO_236-101_1x01_P5.00mm_45Degree
K1E09, K1E11: SLTpad; SLT
M1A09, M1A11, M1C09, M1D09, M1E09, M1E11: SLTpad; SLT
N1A09, N1A11: SLTpad; SLT
R1: 330k; R_0805_2012Metric
R3, R4, R5, R6, R11, R12, R13, R14, R15, R16, R17, R18, R19, R20, R21, R22, R23, R24: 470; R_0805_2012Metric
R9: 47k; R_0805_2012Metric
R10: 10K; R_0805_2012Metric
S0, S1, S2, S3, S4, S5, S6, S7, S8, S9, S10, S11, S12, S13, S14, S15, S16, S17: SLTpad; SLT
SAR3, SAR4, SAR5, SAR6, SAR7, SAR8, SAR9, SAR10, SAR11, SAR12, SAR13, SAR14, SAR15: SLTpad; SLT
SR1: SLTpad; SLT
SS1: SLTpad; SLT
SU1: SLTpad; SLT
SW1: SLTpad; SLT
U1: MR0A16AYS35; MR0A16A
U2, U3: SN74LV240APWR; sn74lvc244a
U4, U5: LDL1117; SOT-223-3_TabPin2
U6: 74LVC1G14; SOT-23-5_HandSoldering
U7, U8, U9, U10, U11: 74LVC08A; TSSOP-14_4.4x5mm_P0.65mm
U14: 74HC00; SOIC-14_3.9x8.7mm_P1.27mm
U15, U16, U17, U18: 74HC86; TSSOP-14_4.4x5mm_P0.65mm

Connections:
+3.3V: C5.1, C6.1, C12.1, C13.1, C16.1, C17.1, C18.1, C19.1, C20.1, C21.1, C24.1, C25.1, C26.1, C27.2, C28.2, R1.1, U1.11 (VDD), U1.27 (VDD), U1.33 (VDD), U2.20 (VCC), U3.20 (VCC), U4.2 (VO), U6.5 (VCC), U7.14 (VCC), U8.14 (VCC), U9.14 (VCC), U10.14 (VCC), U11.9, U11.10, U11.12, U11.13, U11.14 (VCC), U14.10, U14.14 (VCC), U15.14 (VCC), U16.14 (VCC), U17.14 (VCC), U18.10, U18.13, U18.14 (VCC)
+SW: G1E11.1, J3.3, SW1.1
/+12V: C1.1, C4.1, J5.1, R9.1, U4.3 (VI), U5.3 (VI)
GND: C1.2, C2.2, C3.2, C4.2, C5.2, C6.2, C12.2, C13.2, C16.2, C17.2, C18.2, C19.2, C20.2, C21.2, C24.2, C25.2, C26.2, C27.1, C28.1, IC1.2 (E), IC2.2 (E), IC3.2 (E), IC4.2 (E), IC5.2 (E), IC6.2 (E), IC7.2 (E), IC8.2 (E), IC9.2 (E), IC10.2 (E), IC11.2 (E), IC12.2 (E), IC13.2 (E), IC14.2 (E), IC15.2 (E), IC16.2 (E), IC17.2 (E), IC18.2 (E), J4.9, J5.2, J6.1, R10.2, U1.1 (A0), U1.2 (A1), U1.3 (A2), U1.12 (VSS), U1.26 (VSS), U1.34 (VSS), U1.39 (~LB), U1.40 (~UB), U2.10 (GND), U3.10 (GND), U4.1 (GND), U5.1 (GND), U6.3 (GND), U7.7 (GND), U8.7 (GND), U9.7 (GND), U10.7 (GND), U11.7 (GND), U14.7 (GND), U15.7 (GND), U16.7 (GND), U17.7 (GND), U18.7 (GND)
unnamed: A1E09.1, B0.1, U2.2 (1A1)
unnamed: A1E11.1, IC14.3 (C), S3.1
unnamed: B1.1, U2.4 (1A2)
unnamed: B2.1, U2.6 (1A3)
unnamed: B3.1, U2.8 (1A4)
unnamed: B4.1, U2.11 (2A1)
unnamed: B5.1, U2.13 (2A2)
unnamed: B6.1, U2.15 (2A3)
unnamed: B7.1, U2.17 (2A4)
unnamed: B8.1, U3.2 (1A1)
unnamed: B9.1, U3.4 (1A2)
unnamed: B10.1, K1E09.1, U3.6 (1A3)
unnamed: B11.1, U3.8 (1A4)
unnamed: B12.1, U3.11 (2A1)
unnamed: B13.1, U3.13 (2A2)
unnamed: B14.1, U3.15 (2A3)
unnamed: B15.1, U3.17 (2A4)
unnamed: C1A11.1, IC10.3 (C), S7.1
unnamed: C3.1, R1.2, U6.2
unnamed: G1E09.1, SAR3.1, U1.4 (A3)
unnamed: IC1.1 (B), R3.2
unnamed: IC1.3 (C), M1A11.1, S17.1
unnamed: IC2.1 (B), R4.2
unnamed: IC2.3 (C), S16.1
unnamed: IC3.1 (B), R5.1
unnamed: IC3.3 (C), S15.1
unnamed: IC4.1 (B), R6.1
unnamed: IC4.3 (C), S14.1
unnamed: IC5.1 (B), R11.2
unnamed: IC5.3 (C), K1E11.1, S13.1
unnamed: IC6.1 (B), R12.2
unnamed: IC6.3 (C), S12.1
unnamed: IC7.1 (B), R13.2
unnamed: IC7.3 (C), S4.1
unnamed: IC8.1 (B), R14.2
unnamed: IC8.3 (C), S5.1
unnamed: IC9.1 (B), R15.1
unnamed: IC9.3 (C), S6.1
unnamed: IC10.1 (B), R16.2
unnamed: IC11.1 (B), R20.1
unnamed: IC11.3 (C), S0.1
unnamed: IC12.1 (B), R19.1
unnamed: IC12.3 (C), S1.1
unnamed: IC13.1 (B), R18.1
unnamed: IC13.3 (C), S2.1
unnamed: IC14.1 (B), R17.1
unnamed: IC15.1 (B), R21.1
unnamed: IC15.3 (C), S8.1
unnamed: IC16.1 (B), R22.1
unnamed: IC16.3 (C), S9.1
unnamed: IC17.1 (B), R23.1
unnamed: IC17.3 (C), S10.1
unnamed: IC18.1 (B), R24.1
unnamed: IC18.3 (C), S11.1
unnamed: J1.1, U7.2
unnamed: J1.2, U7.5
unnamed: J1.3, U7.10
unnamed: J1.4, U7.13
unnamed: J1.5, U8.2
unnamed: J1.6, U8.5
unnamed: J1.7, U8.10
unnamed: J1.8, U8.13
unnamed: J1.9, U9.2
unnamed: J1A11.1, SAR10.1, U1.23 (A10)
unnamed: J2.1, U9.5
unnamed: J2.2, U9.10
unnamed: J2.3, U9.13
unnamed: J2.4, U10.2
unnamed: J2.5, U10.5
unnamed: J2.6, U10.10
unnamed: J2.7, U10.13
unnamed: J2.8, U11.5
unnamed: J2.9, U11.2
unnamed: J3.1, U14.8
unnamed: J3.2, SR1.1
unnamed: J3.4, U1.17 (~W)
unnamed: J3.5, U1.41 (~G)
unnamed: J3.6, U1.6 (~E)
unnamed: J3.8, U2.1 (~1OE), U2.19 (~2OE), U3.1 (~1OE), U3.19 (~2OE)
unnamed: C2.1, J3.9, U5.2 (VO)
unnamed: J4.8, U6.4
unnamed: R3.1, U11.6
unnamed: R4.1, U11.3
unnamed: R5.2, U10.11
unnamed: R6.2, U10.8
unnamed: R9.2, R10.1, U14.2
unnamed: R11.1, U10.6
unnamed: R12.1, U10.3
unnamed: R13.1, U8.3
unnamed: R14.1, U8.6
unnamed: R15.2, U8.8
unnamed: R16.1, U8.11
unnamed: R17.2, U7.11
unnamed: R18.2, U7.8
unnamed: R19.2, U7.6
unnamed: R20.2, U7.3
unnamed: R21.2, U9.3
unnamed: R22.2, U9.6
unnamed: R23.2, U9.8
unnamed: R24.2, U9.11
unnamed: SAR4.1, U1.5 (A4)
unnamed: SAR5.1, U1.18 (A5)
unnamed: SAR6.1, U1.19 (A6)
unnamed: SAR7.1, U1.20 (A7)
unnamed: SAR8.1, U1.21 (A8)
unnamed: SAR9.1, U1.22 (A9)
unnamed: SAR11.1, U1.24 (A11)
unnamed: SAR12.1, U1.25 (A12)
unnamed: SAR13.1, U1.42 (A13)
unnamed: SAR14.1, U1.43 (A14)
unnamed: SAR15.1, U1.44 (A15)
unnamed: SU1.1, U14.1
unnamed: U1.7 (DQL0), U2.18 (1Y1), U7.1, U15.1
unnamed: U1.8 (DQL1), U2.16 (1Y2), U7.4, U15.2
unnamed: U1.9 (DQL2), U2.14 (1Y3), U7.9, U15.4
unnamed: U1.10 (DQL3), U2.12 (1Y4), U7.12, U15.5
unnamed: U1.13 (DQL4), U2.9 (2Y1), U8.1, U15.9
unnamed: U1.14 (DQL5), U2.7 (2Y2), U8.4, U15.10
unnamed: U1.15 (DQL6), U2.5 (2Y3), U8.9, U15.12
unnamed: U1.16 (DQL7), U2.3 (2Y4), U8.12, U15.13
unnamed: U1.29 (DQU8), U3.18 (1Y1), U9.1, U16.1
unnamed: U1.30 (DQU9), U3.16 (1Y2), U9.4, U16.2
unnamed: U1.31 (DQU10), U3.14 (1Y3), U9.9, U16.4
unnamed: U1.32 (DQU11), U3.12 (1Y4), U9.12, U16.5
unnamed: U1.35 (DQU12), U3.9 (2Y1), U10.1, U16.9
unnamed: U1.36 (DQU13), U3.7 (2Y2), U10.4, U16.10
unnamed: U1.37 (DQU14), U3.5 (2Y3), U10.9, U16.12
unnamed: U1.38 (DQU15), U3.3 (2Y4), U10.12, U16.13
unnamed: U11.1, U18.11
unnamed: U11.4, U18.8
unnamed: U14.3, U14.9
unnamed: U15.3, U17.1
unnamed: U15.6, U17.2
unnamed: U15.8, U17.4
unnamed: U15.11, U17.5
unnamed: U16.3, U17.9
unnamed: U16.6, U17.10
unnamed: U16.8, U17.12
unnamed: U16.11, U17.13
unnamed: U17.3, U18.1
unnamed: U17.6, U18.2
unnamed: U17.8, U18.4
unnamed: U17.11, U18.5
unnamed: U18.6, U18.9
unnamed: U18.3, U18.12

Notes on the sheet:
+12V
+SW
3.3V regulator
+Storage Read
Pass Bx to DQx
CMOD S7 upper right connector
1 2 3 4 5 6 7 8 9
-SW
+Storage Write
Odd parity P2
(~P2)*RQ
GateB2M
SPARE
braided ground
CMOD S7 upper left connector
33 32 31 30 20 28 27 26 25
+12
reset
MRAM
+SR
(~P1)*RQ
ground
~(Odd parity P1)
48 47 46 45 44 43 42 41 40
DQx*RQ
+Storage Select
SU*12V
+Storage Use
+SU*12V
16 17 18 19 20 21 22 23 24
5V regulator
Odd parity P1
~(Odd parity P2)
CMOD S7 lower connectors

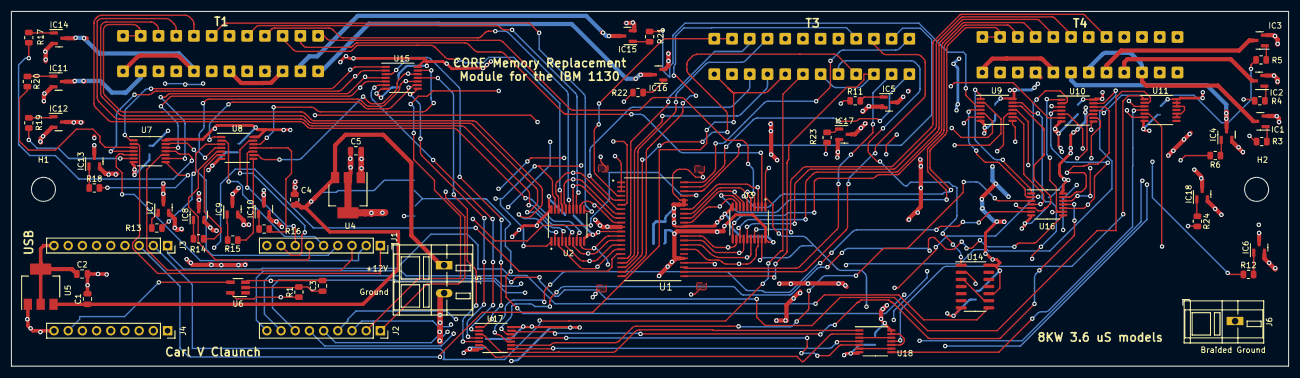
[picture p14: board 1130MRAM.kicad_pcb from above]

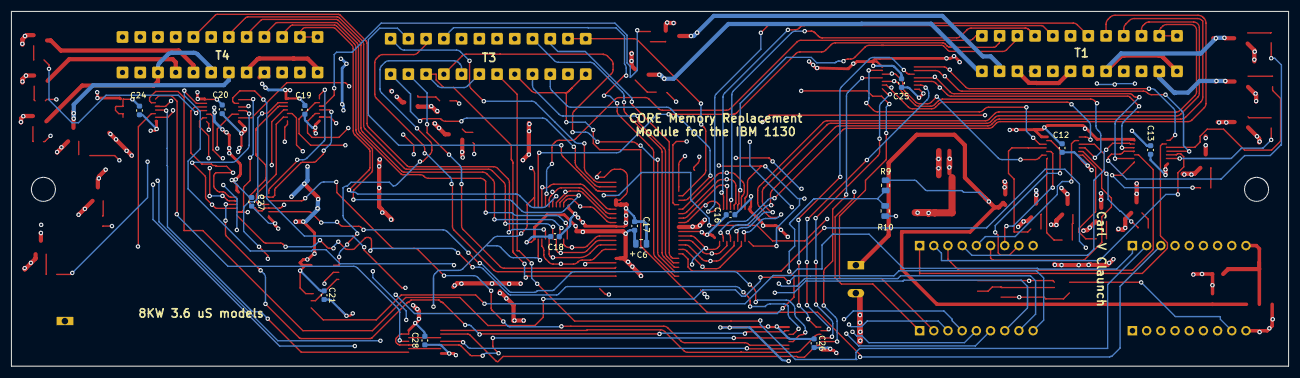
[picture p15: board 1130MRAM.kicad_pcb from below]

Board: 4 copper layers, 228.6 x 63.5 mm, 154 parts (88 on the bottom side), 149 nets.

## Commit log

2025-07-27 Initial design KiCAD files
    [1130MRAM.kicad_pcb, 1130MRAM.kicad_sch]
2025-07-28 Completed design V1
    prior to verification
    [1130MRAM.kicad_pcb, 1130MRAM.kicad_sch]
2025-07-28 New document
    Describes the logic and operation of the board.
2025-07-29 Latest version with fixes
    fixed parity circuits, went to 4 layer board
    [1130MRAM.kicad_pcb, 1130MRAM.kicad_sch]
2025-07-30 Annotations and cleanup
    [1130MRAM.kicad_pcb, 1130MRAM.kicad_sch]
2025-07-30 Corrections to design
    [1130MRAM.kicad_pcb, 1130MRAM.kicad_sch]
2025-07-30 Updated Bill of Materials
    Includes Digikey product numbers, prices and quantities.
    Almost complete
    [BOM.csv]
2025-08-13 Debugged version of KiCAD files
    Created project library for the symbols and footprints used with this design
    [1130MRAM.kicad_pcb, 1130MRAM.kicad_sch]
2025-08-13 Cleaned up after bench testing
    also put symbols and footprints into project libraries
2025-09-18 Backfeed protection circuit added
    Blocks backfeed of voltage from 1130 inputs to the PCB unless the +12V power rail is active
2025-09-18 Now with onboard regulator for 3.3V
2025-09-18 Onboard voltage regulator change
2025-09-27 Post debugging version
    tie together pins that have duplicate signals on connectors T1, T3 and T4, as was done on the SLT backplane we are replacing. Gets the control, address, data and sense signals correctly routed from 1130 CPU to the PCB circuitry.
2025-09-27 Post debugging version
    Handles duplicate pins on cables T1, T3 and T4 that are only bridged on the IBM SLT backplane we are replacing with this board. Gets control, address, data and sense signals to the circuitry on the P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
    [1130MRAM.kicad_pcb, 1130MRAM.kicad_sch]
2025-10-03 Switched to 74LCX38 for better output drive
    prior chip had insufficient current sink to set the 1130 flip flop
2025-10-03 Switch to 74LCX38 for better output drive
    prior open drain gate had insufficent current sink capacity to set the 1130's B register flipflop
    [1130MRAM.kicad_pcb, 1130MRAM.kicad_sch]
2025-10-03 Updated Bill of Materials
    new power, new low side ground lift circuit, change to 74LCX38 chips, plus tariff increase on PCBs
    [BOM.csv]
2025-10-10 Tweaks
    Changed to make soldering of filter capacitors easier next to certain chips
    [1130MRAM.kicad_pcb]
2025-10-13 Corrected defect in design
    Prior design optimization led to a failure mode that is experienced on the IBM 1130. Corrected the issue.
    [1130MRAM.kicad_pcb, 1130MRAM.kicad_sch]
2025-11-12 Newest version of the PCB
    based on testing with the 1130, the PCB was modified substantially
    [1130MRAM.kicad_pcb, 1130MRAM.kicad_sch]
2025-11-12 Newest version of PCB design documented
2025-11-12 Corresponding to newest version of PCB
    [BOM.csv]
2025-12-22 Changes after testing
    tweaks to design, components, and documentation.
    [1130MRAM.kicad_pcb, 1130MRAM.kicad_sch, BOM.csv]
2026-03-19 New version leveraging FPGA
    Changed board to be driven by an FPGA
    [1130MRAM-F_Paste.dxf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]
2026-03-19 files associated with new design of board
2026-03-19 files associated with new board design
2026-07-04 Change base resistors
    minot component cahnge
    [1130MRAM.kicad_sch]
2026-07-05 Final version of the board and bill of material
    [1130MRAM-B_Cu.gbr, 1130MRAM-B_Mask.gbr, 1130MRAM-B_Paste.gbr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]
2026-07-05 Delete 1130MRAM.zip
    uploaded individual gerber and hole files rather than zip file
2026-07-11 Improved PCB design
    improved ground paths for MRAM chiip, added 10uF decoupling capacitor next to .1uF capacitor.
    opened solder mask for four ground pads to solder magnetic shield over chip
    [1130MRAM-B_Cu.gbr, 1130MRAM-B_Mask.gbr, 1130MRAM-B_Paste.gbr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]
2026-07-12 After final debugging
    Added braided ground wire necessary to avoid ground bounce due to high impedance of the normal stranded wire for the ground line.
    [BOM.csv]
2026-07-12 Delete 1130MRAM-F_Paste.dxf
    extraneous file
    [1130MRAM-F_Paste.dxf]
2026-07-12 Delete 1130MRAM.kicad_prl
    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
